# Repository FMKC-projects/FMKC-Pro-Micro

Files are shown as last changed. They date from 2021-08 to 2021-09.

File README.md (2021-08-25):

# FMKC Pro Micro
The FMKC Pro Micro is a fork of the Goldfish type-C pro micro Rev C. The reason why this is forked is that at the time of writing, type-C Pro Micros are either A) really expensive, or B) ugly looking. This fork is planned to be a community-themes pro micro and hence also openly shared. We'll try to include everything so that you could make your own PCBWay (or similar) or order.

## Risks
At the time of writing, we haven't yet done a order of this fork. Despite when this run has been done and the files are "ready", you are still using this at your own risk.

## Repo Contents
**/cad** - KiCad source files.  
**/doc** - Schematics
**/bom** - The BOM-file as .xslx (or some other format)

## License Information
Released under the Creative Commons Attribution Share-Alike 4.0 License.  
https://creativecommons.org/licenses/by-sa/4.0/  

Original Arduino Mini Design by Team Arduino.  
Arduino Pro Mini Design by Spark Fun Electronics.  
Pro Micro Design by Spark Fun Electronics.  
Goldfish Design by Dr Derivative.  

## Related Projects
* [Alvaro](https://github.com/Ariamelon/Alvaro) by Ariamelon - A modified goldfish using 0603 components instead of 0402
* [Comet](https://github.com/vattern/comet) by Tokas - A modified goldfish using a different USB-C connector
* [Goldfish-clone-JLCPCB](https://github.com/JeremyJStarcher/Goldfish-clone-JLCPCB) by Jeremy J Starcher - A modified goldfish designed to meet JLCPCB's assembly requirements
* Elite-C from keeb.io - An unrelated and closed source project with similar design goals

## Potential vendors
* Potential single units available after production by [olli.works](https://olli.works)

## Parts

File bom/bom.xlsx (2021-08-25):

Item # | *Ref Des | *Qty | Manufacturer | *Mfg Part # | Description / Value | *Package | Type | Your Instructions / Notes
 | R5,R4 | 2 | RALEC | RTT0222R0FTH | 1/16W ±1% ±100ppm/℃ 22Ω 0402 Chip Resistor - Surface Mount ROHS | 0402 | SMD | https://lcsc.com/product-detail/Chip-Resistor-Surface-Mount_RALEC-RTT0222R0FTH_C102905.html
 | C9 | 1 | FH(Guangdong Fenghua Advanced Tech) | 0402X105M6R3NT | X5R 6.3V ±20% 1uF 0402 Multilayer Ceramic Capacitors MLCC - SMD/SMT ROHS | 0402 | SMD | https://lcsc.com/product-detail/Multilayer-Ceramic-Capacitors-MLCC-SMD-SMT_FH-Guangdong-Fenghua-Advanced-Tech-0402X105M6R3NT_C301999.html
 | C1,C2,C3,C4,C5,C10 | 6 | FH(Guangdong Fenghua Advanced Tech) | 0402B104K500NT | X7R 100nF ±10% 50V 0402 Multilayer Ceramic Capacitors MLCC - SMD/SMT ROHS | 0402 | SMD | https://lcsc.com/product-detail/Multilayer-Ceramic-Capacitors-MLCC-SMD-SMT_FH-Guangdong-Fenghua-Advanced-Tech-0402B104K500NT_C110251.html
 | R3,R6 | 2 | RALEC | RTT021002FTH | 1/16W ±1% ±100ppm/℃ 10kΩ 0402 Chip Resistor - Surface Mount ROHS | 0402 | SMD | https://lcsc.com/product-detail/Chip-Resistor-Surface-Mount_RALEC-RTT021002FTH_C102749.html
 | C6 | 1 | FH(Guangdong Fenghua Advanced Tech) | 0402X475K100NT | X5R ±10% 10V 4.7uF 0402 Multilayer Ceramic Capacitors MLCC - SMD/SMT ROHS | 0402 | SMD | https://lcsc.com/product-detail/Multilayer-Ceramic-Capacitors-MLCC-SMD-SMT_FH-Guangdong-Fenghua-Advanced-Tech-0402X475K100NT_C191541.html
 | U1 | 1 | Microchip Tech | ATMEGA32U4-MU | 2.7V ~ 5.5V 8-Bit AVR 16MHz FLASH QFN-44_7x7x05P ATMEL & AVR ROHS | QFN-44_7x7x05P | SMD | https://lcsc.com/product-detail/ATMEL-AVR_Microchip-Tech-ATMEGA32U4-MU_C112161.html
 | X1 | 1 | Seiko Epson | Q22FA2380186800 | SMD3225-4P Crystals ROHS | SMD3225-4P | SMD | https://lcsc.com/product-detail/Crystals_Seiko-Epson-Q22FA2380186800_C841681.html
 | C7,C8 | 2 | FH(Guangdong Fenghua Advanced Tech) | 0402CG220F500NT | C0G ±1% 50V 22pF 0402 Multilayer Ceramic Capacitors MLCC - SMD/SMT ROHS | 0402 | SMD | https://lcsc.com/product-detail/Multilayer-Ceramic-Capacitors-MLCC-SMD-SMT_FH-Guangdong-Fenghua-Advanced-Tech-0402CG220F500NT_C190090.html
 | R1,R2 | 2 | RALEC | RTT025101FTH | ±1% 1/16W ±100ppm/℃ 5.1kΩ 0402 Chip Resistor - Surface Mount ROHS | '0402 | SMD | https://lcsc.com/product-detail/Chip-Resistor-Surface-Mount_RALEC-RTT025101FTH_C103079.html
 | J1 | 1 | HRS(Hirose) | CX70M-24P1 | USB Connectors ROHS |  | SMD | https://lcsc.com/product-detail/USB-Connectors_HRS-Hirose-CX70M-24P1_C778726.html
 | D1 | 1 | Diodes Incorporated | DFLS260Q-7 | PowerDI123 Schottky Barrier Diodes (SBD) ROHS | PowerDI123 | SMD | https://lcsc.com/product-detail/span-style-background-color-ff0-Schottky-span-Barrier-Diodes-SBD_Diodes-Incorporated-DFLS260Q-7_C526562.html

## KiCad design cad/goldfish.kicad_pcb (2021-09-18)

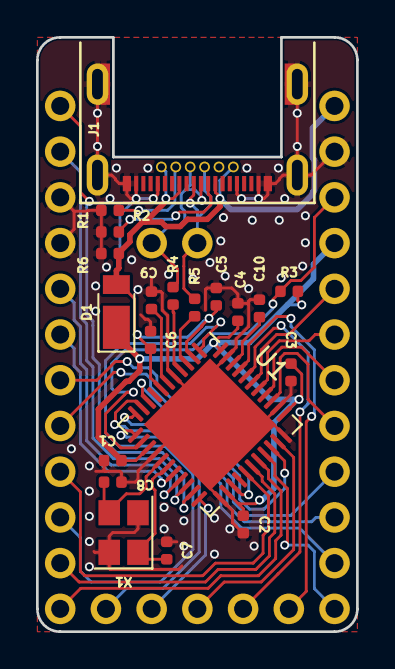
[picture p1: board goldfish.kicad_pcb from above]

Board: 2 copper layers, 17.8 x 33.0 mm, 24 parts (0 on the bottom side), 37 nets.

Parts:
C1, C2, C3, C4, C5, C10: 0u1; C_0402_1005Metric
C6: 4u7; C_0402_1005Metric
C7, C8: 22p; C_0402_1005Metric
C9: 1u; C_0402_1005Metric
D1: D_Schottky; D_PowerDI-123
J1: USB-C; CX70M-24P1
J2: 01x02; Pins2
J3, J4: 01x12; Pins12
J5: 01x05; Pins5
R1, R2: 5k1; R_0402_1005Metric
R3, R6: 10k; R_0402_1005Metric
R4, R5: 22; R_0402_1005Metric
U1: ATmega32U4; QFN-44-1EP_7x7mm_P0.5mm_EP5.2x5.2mm_FORK
X1: 16MHz; Crystal_SMD_SeikoEpson_FA238-4Pin_3.2x2.5mm

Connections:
/D+: J1.A6, J1.B6, J2.1, R4.2
/D-: J1.A7, J1.B7, J2.2, R5.2
/PB1: J3.9, U1.9
/PB2: J3.11, U1.10
/PB3: J3.10, U1.11
/PB4: J4.2, U1.28
/PB5: J4.1, U1.29
/PB6: J3.12, U1.30
/PB7: J5.5, U1.12
/PC6: J4.5, U1.31
/PC7: J5.3, U1.32
/PD0: J4.7, U1.18
/PD1: J4.8, U1.19
/PD2: J4.11, U1.20
/PD3: J4.12, U1.21
/PD4: J4.6, U1.25
/PD5: J5.4, U1.22
/PD7: J4.4, U1.27
/PE6: J4.3, U1.1
/PF0: J5.1, U1.41
/PF1: J5.2, U1.40
/PF4: J3.5, U1.39
/PF5: J3.6, U1.38
/PF6: J3.7, U1.37
/PF7: J3.8, U1.36
/RESET: J3.3, R3.1, U1.13
GND: C1.2, C2.2, C3.2, C4.2, C5.2, C6.2, C7.2, C8.2, C9.2, C10.2, J1.A1, J1.A12, J1.B1, J1.B12, J1.S1, J3.2, J4.9, J4.10, R1.1, R2.1, R6.1, U1.5, U1.15, U1.23, U1.33, U1.35, U1.43, U1.45, X1.2, X1.4
unnamed: C7.1, U1.17, X1.1
unnamed: C8.1, U1.16, X1.3
unnamed: C9.1, U1.6
unnamed: C10.1, U1.42
unnamed: J1.A5, R1.2
unnamed: J1.B5, R2.2
unnamed: R4.1, U1.4
unnamed: R5.1, U1.3
VBUS: C5.1, C6.1, D1.2, J1.A4, J1.A9, J1.B4, J1.B9, J3.1, R6.2, U1.2, U1.7
VCC: C1.1, C2.1, C3.1, C4.1, D1.1, J3.4, R3.2, U1.14, U1.24, U1.34, U1.44

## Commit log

2021-08-25 Updated README, added preliminary BOM
    [bom.xlsx]
2021-08-25 removed goldfish silk
    [goldfish.kicad_pcb]
2021-08-29 Making letters small
    [goldfish.kicad_pcb]
2021-09-01 adding silks
    [goldfish.kicad_pcb]
2021-09-03 tyty-c addition test
    [goldfish.kicad_pcb]
2021-09-18 idk plotted things, pcb artworks etc random work, should prolly gitignore plot-folder but cba :D
    [goldfish-B_Courtyard.gbr, goldfish-B_Cu.gbl, goldfish-B_Fab.gbr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]
